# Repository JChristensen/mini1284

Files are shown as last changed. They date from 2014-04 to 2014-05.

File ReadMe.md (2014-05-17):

# The Mighty Mini 1284P #

A minimal breadboard-friendly design for the ATmega1284P MCU, named after [maniacbug's "mighty-1284p" Arduino core](http://goo.gl/iBJMnJ), in recognition of his contribution to the Arduino community. It has all necessary support components, ICSP and FTDI headers, and all GPIO pins are brought out to headers.

05May2014 - An updated version of maniacbug's mighty-1284p core based on Arduino 1.0.5 is available [here](http://goo.gl/l7cPbX).

Printed circuit boards can be [ordered through OSH Park](http://goo.gl/ZxooPW).

A bill of materials is [available on Mouser](http://goo.gl/hXERzO).

I'd be interested to hear from anyone that builds one.

#### CC BY-SA ####
"The Mighty Mini 1284P" by Jack Christensen is licensed under [CC BY-SA 4.0](http://creativecommons.org/licenses/by-sa/4.0/).

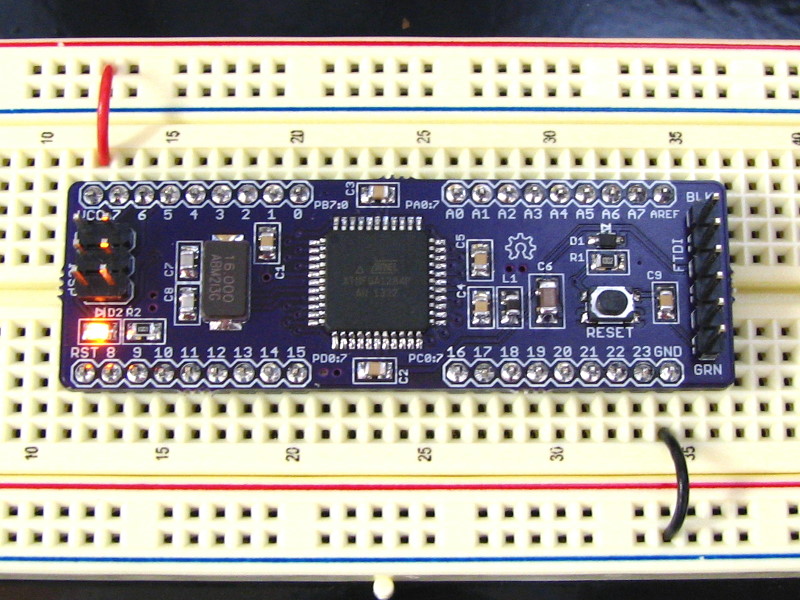
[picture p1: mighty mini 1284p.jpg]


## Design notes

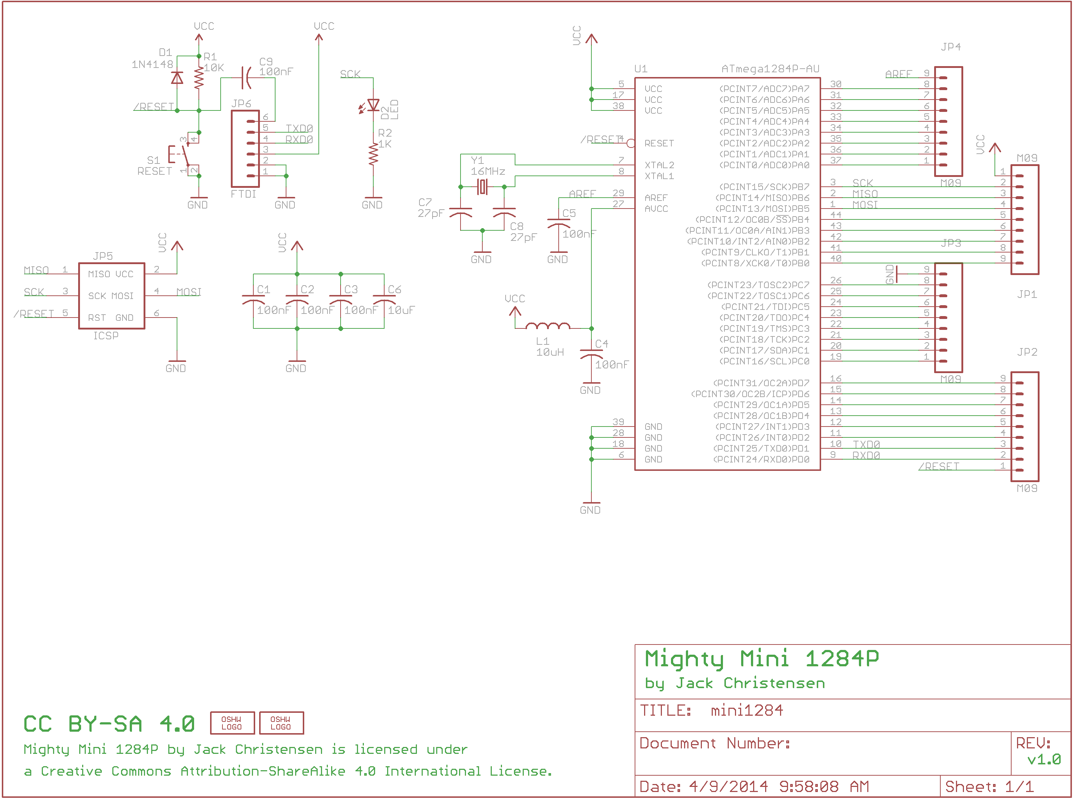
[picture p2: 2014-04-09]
schematic.png

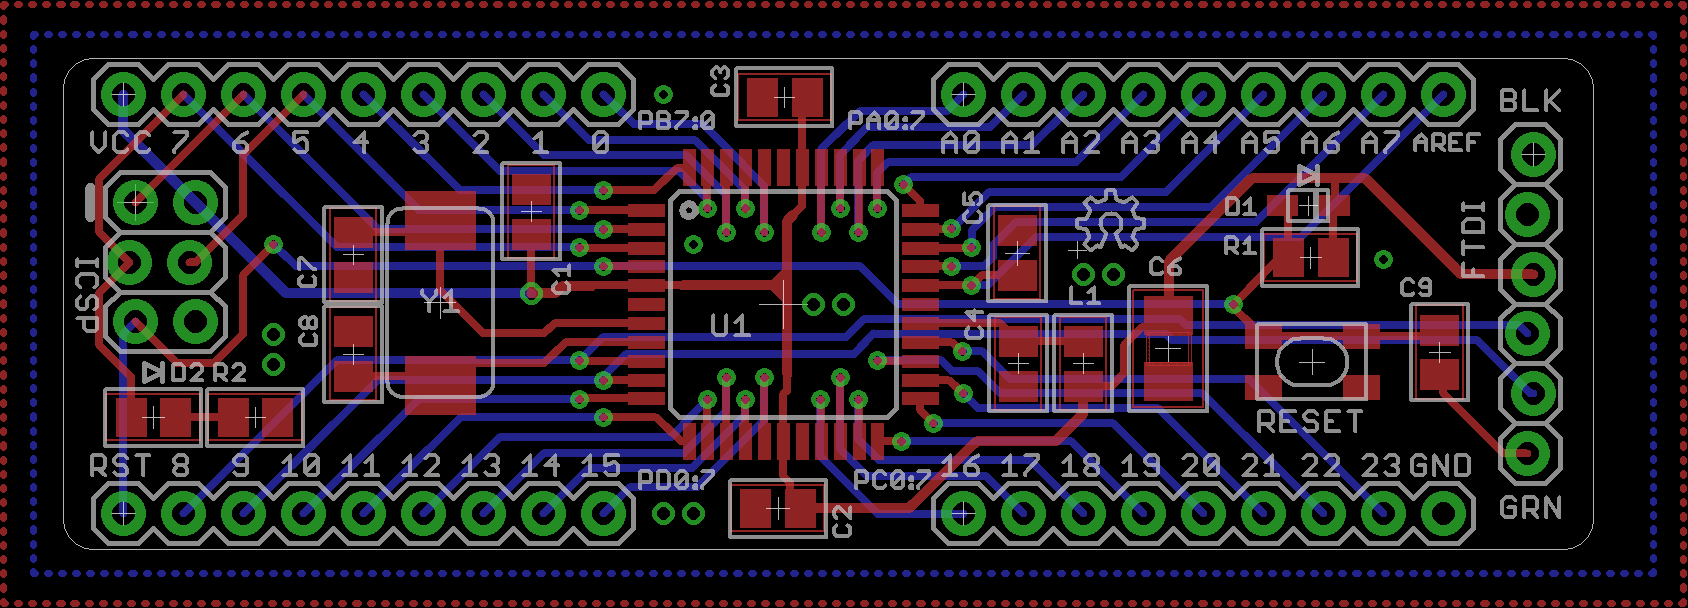
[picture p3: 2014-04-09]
board.png

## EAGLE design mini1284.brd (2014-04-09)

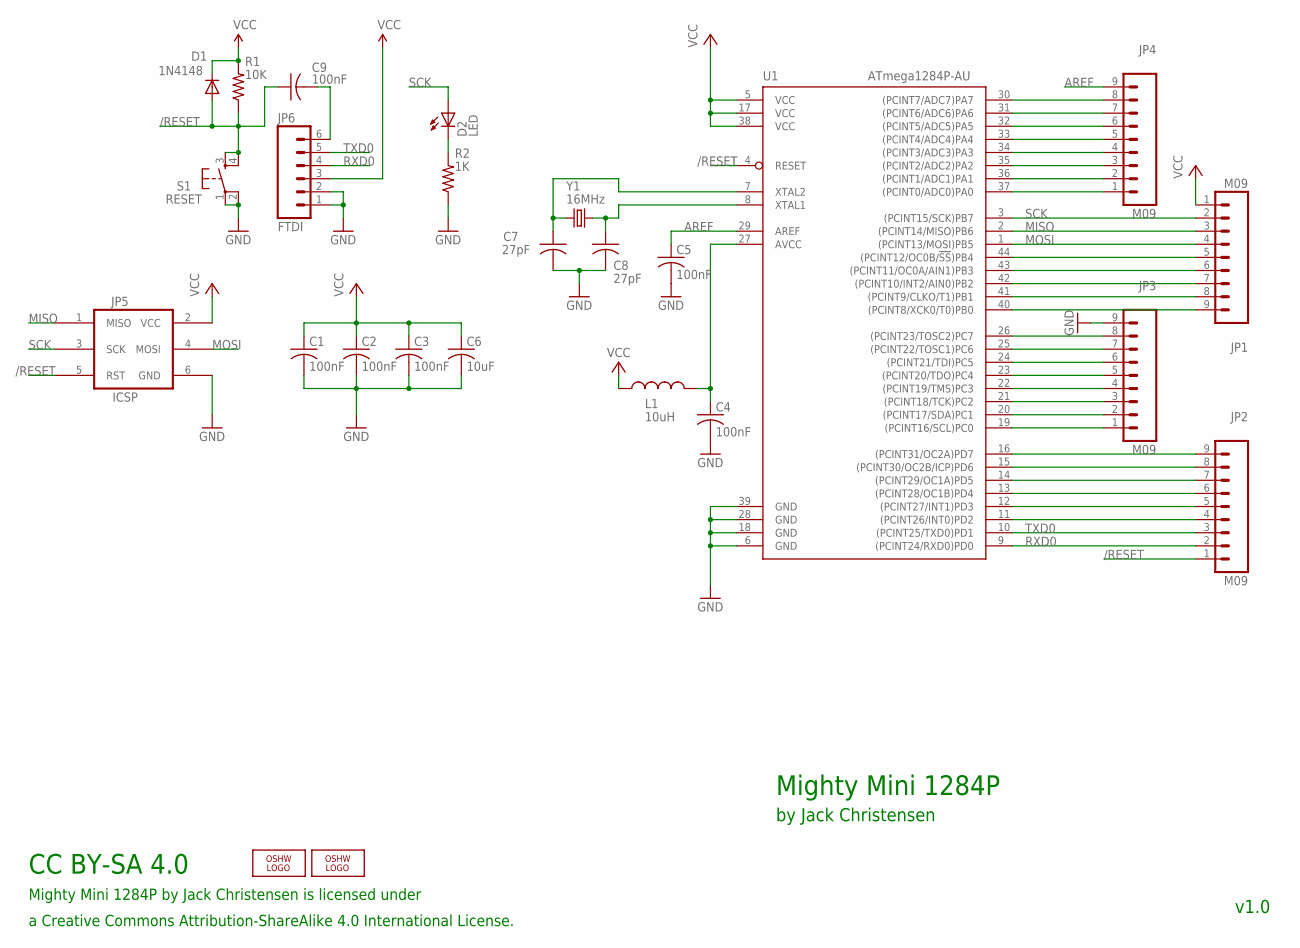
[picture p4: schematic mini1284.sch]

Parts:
C1, C2, C3, C4, C5, C9: 100nF; M0805
C6: 10uF; M1206
C7, C8: 27pF; M0805
D1: 1N4148; SOD-323F-A
D2: LED; D0805A
JP1, JP2, JP3, JP4: M09; 1X09
JP5: ICSP; 2X3_LOCK
JP6: FTDI; 1X06_LOCK
L1: 10uH; M0805
LOGO1: OSHW_LOGO_8MILX0150-NT; OSHW_8X150_NOTEXT
LOGO2: OSHW_LOGO_6MILX0100-NT; OSHW_6X100_NOTEXT
R1: 10K; M0805
R2: 1K; M0805
S1: RESET; PTS810
U1: ATmega1284P-AU; TQFP44
Y1: 16MHz; CRYSTAL-ABRACON-ABM2

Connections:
/RESET: C9.1, D1.A, JP2.1, JP5.5 (RST), R1.1, S1.3 (S), S1.4 (S1), U1.4 (RESET)
AREF: C5.1, JP4.9, U1.29 (AREF)
GND: C1.2, C2.2, C3.2, C4.2, C5.2, C6.2, C7.2, C8.2, JP3.9, JP5.6 (GND), JP6.1, JP6.2, R2.1, S1.1, S1.2 (P1), U1.6 (GND), U1.18 (GND), U1.28 (GND), U1.39 (GND)
MISO: JP1.3, JP5.1 (MISO), U1.2 ((PCINT14/MISO)PB6)
MOSI: JP1.4, JP5.4 (MOSI), U1.1 ((PCINT13/MOSI)PB5)
unnamed: C4.1, L1.2, U1.27 (AVCC)
unnamed: C8.1, U1.8 (XTAL1), Y1.P$2 (2)
unnamed: C7.1, U1.7 (XTAL2), Y1.P$1 (1)
unnamed: JP2.4, U1.11 ((PCINT26/INT0)PD2)
unnamed: JP1.5, U1.44 ((PCINT12/OC0B/!SS!)PB4)
unnamed: JP1.6, U1.43 ((PCINT11/OC0A/AIN1)PB3)
unnamed: JP1.7, U1.42 ((PCINT10/INT2/AIN0)PB2)
unnamed: JP1.8, U1.41 ((PCINT9/CLKO/T1)PB1)
unnamed: JP1.9, U1.40 ((PCINT8/XCK0/T0)PB0)
unnamed: JP2.5, U1.12 ((PCINT27/INT1)PD3)
unnamed: JP2.6, U1.13 ((PCINT28/OC1B)PD4)
unnamed: JP2.7, U1.14 ((PCINT29/OC1A)PD5)
unnamed: JP2.8, U1.15 ((PCINT30/OC2B/ICP)PD6)
unnamed: JP2.9, U1.16 ((PCINT31/OC2A)PD7)
unnamed: JP3.1, U1.19 ((PCINT16/SCL)PC0)
unnamed: JP3.2, U1.20 ((PCINT17/SDA)PC1)
unnamed: JP3.3, U1.21 ((PCINT18/TCK)PC2)
unnamed: JP3.4, U1.22 ((PCINT19/TMS)PC3)
unnamed: JP3.5, U1.23 ((PCINT20/TDO)PC4)
unnamed: JP3.6, U1.24 ((PCINT21/TDI)PC5)
unnamed: JP3.7, U1.25 ((PCINT22/TOSC1)PC6)
unnamed: JP3.8, U1.26 ((PCINT23/TOSC2)PC7)
unnamed: JP4.1, U1.37 ((PCINT0/ADC0)PA0)
unnamed: JP4.2, U1.36 ((PCINT1/ADC1)PA1)
unnamed: JP4.3, U1.35 ((PCINT2/ADC2)PA2)
unnamed: JP4.4, U1.34 ((PCINT3/ADC3)PA3)
unnamed: JP4.5, U1.33 ((PCINT4/ADC4)PA4)
unnamed: JP4.6, U1.32 ((PCINT5/ADC5)PA5)
unnamed: JP4.7, U1.31 ((PCINT6/ADC6)PA6)
unnamed: JP4.8, U1.30 ((PCINT7/ADC7)PA7)
unnamed: D2.K (C), R2.2
RST: C9.2, JP6.6
RXD0: JP2.2, JP6.4, U1.9 ((PCINT24/RXD0)PD0)
SCK: D2.A, JP1.2, JP5.3 (SCK), U1.3 ((PCINT15/SCK)PB7)
TXD0: JP2.3, JP6.5, U1.10 ((PCINT25/TXD0)PD1)
VCC: C1.1, C2.1, C3.1, C6.1, D1.K, JP1.1, JP5.2 (VCC), JP6.3, L1.1, R1.2, U1.5 (VCC), U1.17 (VCC), U1.38 (VCC)

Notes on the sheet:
Mighty Mini 1284P
by Jack Christensen
v1.0
Mighty Mini 1284P by Jack Christensen is licensed under
CC BY-SA 4.0
a Creative Commons Attribution-ShareAlike 4.0 International License.

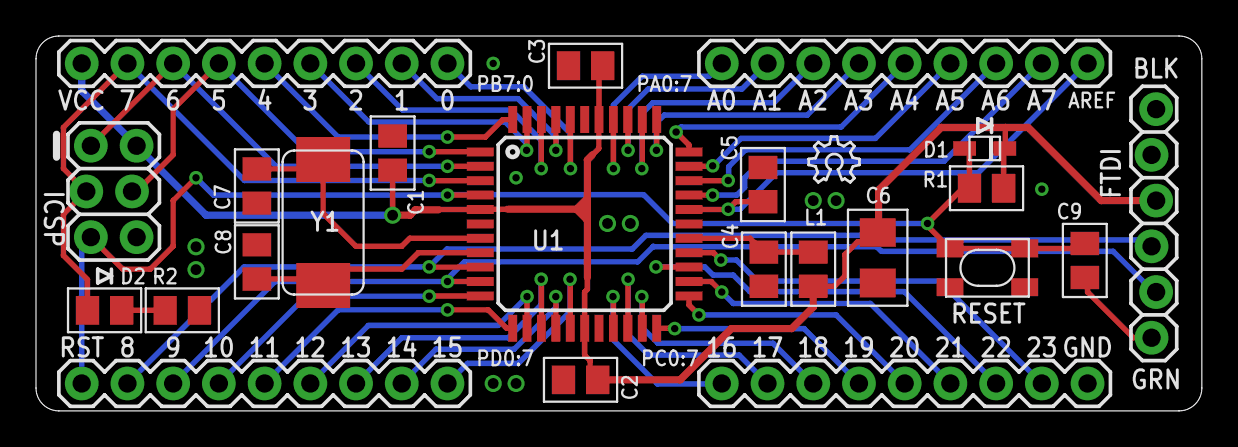
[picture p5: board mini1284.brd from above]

Board: 2 copper layers, 64.8 x 20.8 mm, 25 parts (1 on the bottom side), 41 nets.

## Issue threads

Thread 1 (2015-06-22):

hi, i am happy with the

jar10623, 2015-06-22:
v1.0 now i found at osh park v1.1
what ist different ?
is there a link to the changes?

JChristensen, 2015-06-22:
Only the crystal.
From https://github.com/JChristensen/mini1284/blob/v1.1/ReadMe.md:
"v1.1 differs from v1.0 only in that a different crystal and different value loading capacitors are used."
Check out the png images of the board in each branch and also the links to the bills of materials on Mouser. v1.0 uses [this Abracon crystal](http://www.mouser.com/Search/ProductDetail.aspx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), v1.1 uses [this Epson crystal](http://www.mouser.com/Search/ProductDetail.aspx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). I was hoping to save board space with the Epson crystal but in the end I don't think it saved much, and the Epson crystal is more of a challenge to solder by hand.

jar10623, 2015-06-22:
oh thanks

i think for me the 1.0 is better on the 1.1 i see a 4 pad crystal? ok most of the buyable parts here ar 4 pad crystal, but the 2 pad is solder easyer only the Pads are to small, the buyable Parts here are so short they reached the pads very far. see: https://www.mikrocontroller.net/attachment/255241/mighty_flach1_2.jpg, i wounder only why you routed the FTDI lines on the head,
see on the pic link
face to face to connected were more likely to me, but well done. if you made a 3th one i want a face to face ftdi connect and a smaller pcb for a dil48 socket
http://www.segor.de/bilder/00001eae.jpg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
or a pcb i can put in a 64 motorola 68k socket
http://www.elmotex.de/images/dil-64p.jpg

JChristensen, 2015-06-22:
Good looking boards, thanks for sharing. If I have more boards made, I'd probably just go with v1.0 as well.

Closed 2015-06-22.

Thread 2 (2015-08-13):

need help with optiboot @22.1184 MHz & 921600 Baud

jar10623, 2015-08-13:
befor for all of my 5 mighty 1284p ich use Optiboot for 1M @16MHz

now i change the crytal up to 22.1184 MHz, it works but i must build a new bootloader and i don't know how.

make (winavr) with target atmega1284p give a error

C:\optiboot>make atmega1284
/usr/local/avr/bin/avr-gcc -g -Wall -Os -fno-inline-small-functions -fno-split-w
ide-types -mshort-calls -mmcu=atmega1284p -DF_CPU=22118400L  '-DLED_START_FLASHE
S=3' '-DBAUD_RATE=115200' '-DBIGBOOT'   -c -o optiboot.o optiboot.c
process_begin: CreateProcess(NULL, /usr/local/avr/bin/avr-gcc -g -Wall -Os -fno-
inline-small-functions -fno-split-wide-types -mshort-calls -mmcu=atmega1284p -DF
_CPU=22118400L -DLED_START_FLASHES=3 -DBAUD_RATE=115200 -DBIGBOOT -c -o optiboot
.o optiboot.c, ...) failed.
make (e=3): Das System kann den angegebenen Pfad nicht finden.
make: *** [optiboot.o] Error 3

path error, but wich path why ?
@win there is no /usr/local?

in avr studio 4.18 sr3 is a warning
../optiboot.c:256: warning: 'flash_led' declared 'static' but never defined

but i think that doesn't interessed

build was ok for hex but it doesn't work
i don't know where i must change the baudrate for 921600 Baud  and how put it in the boards.txt in arduino

JChristensen, 2015-08-13:
See https://github.com/Optiboot/optiboot/wiki/CompilingOptiboot

jar10623, 2015-08-14:
sorry that wouldn't help

this show the way to a java use in Arduino, but first
path not found -> the reason name inn Arduino looks like avr-gcc but mein win set path is to winavr gcc so avr-gcc is not found.

ok i have the optiboot sourcen an a aps für studio but there is the
arduino led on PortB1 (1 Problem i found)

i think it dosn't work because no LED
then i think it dosn't work because 22 MHz and low voltage 4,3 to 4,7V

but this is not the reason

Bootloder is build good, programming is good with verify
the mighty started with 5 flashes un LED and 22MHz

but i can not program via Arduino

i try 230400 Bd an put it in the mightys board.txt
same with 115200 Bd

i don't know what can i do, wich #defines wich options are missing?
on Arduino i see this Mistake, every try:

Binäre Sketchgröße: 1.606 Bytes (von einem Maximum von 130.048 Bytes)
avrdude: verification error, first mismatch at byte 0x0002
         0x67 != 0x46
avrdude: verification error; content mismatch

why work mighty with 1 M Bd? do you use avrdude?
why ist there a remark in the source

#if F_CPU > 16000000L
#define BAUD_RATE   230400L // Highest rate Avrdude win32 will support

how it is posible to use 1M and why is my mistake in AVRdude with 115k

jar10623, 2015-08-14:
please would you help me an build

to bootloader
1. 22.1184 MHz @921600 Baud
2. 14.7456 MHz @115200 Baud
and better show me the way (peter frampton)
https://www.youtube.com/watch?v=zLgeTtYwQ7o

i think one MUST be work @arduino

JChristensen, 2015-08-14:
Sorry, I just don't have the time at present. This is a bit off-topic for this repo anyway. Suggest trying the Arduino forum.

jar10623, 2015-08-14:
arduino forum is big, have a link at the right place please?

JChristensen, 2015-08-14:
Microcontrollers
Standalone or alternative microcontrollers, in-system programming, bootloaders, etc.
http://forum.arduino.cc/index.php?board=67.0

jar10623, 2015-08-14:
thanks

jar10623, 2015-08-14:
sorry that the same problem before over arduino, ich can not build.....

but i wounder why you build a 16MHz mighty?
1284p can go um to 20Mhz or maybe 22MHz
for Baudrate it is better to take an baud rate crystal 7.xx 14.xx

16 Mhz is so unusefull

JChristensen, 2015-08-14:
The 1284P provides more flash and SRAM than the 328P, but it's CPU specs are the same; it's not meant to address processing capacity. You're welcome to your opinion but I prefer conservative designs, and certainly not overclocking. Anyway, 20MHz represents only a marginal speed improvement over 16MHz. If I need something with more horsepower, I'd look to double or triple the clock speed and/or go to a 32-bit machine. 16MHz works well with the Arduino ecosystem and I've never had problems with baud rate tolerances.

Closed 2015-08-13.

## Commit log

2014-04-07 Initial commit, before moving MCU.
    [mini1284.brd, mini1284.sch]
2014-04-08 Routing looking pretty good.
    [mini1284.brd, mini1284.sch]
2014-04-09 Routing refinements.
    [mini1284.brd, mini1284.sch]
2014-04-09 Further tweaks.
    [mini1284.brd, mini1284.sch]
2014-04-09 First run sent to fab.
    [mini1284.brd, mini1284.sch]

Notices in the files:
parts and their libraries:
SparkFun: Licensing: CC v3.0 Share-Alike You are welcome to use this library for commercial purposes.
